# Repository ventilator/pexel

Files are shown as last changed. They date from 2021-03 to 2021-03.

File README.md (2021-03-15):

# pexel
Playing around with penrose tilings, in particular _P2_, which consists of _kites_ and _darts_

3D printed shapes, arranged in the _penrose sun_ pattern, LED back light through laser cut acryl with a Raspberry Pi Pico and MicroPython

20 darts and 25 kites, slowly changing their base color, giving a nice, non distracting back ground mood setting, looked a bit like church window style, in the end 

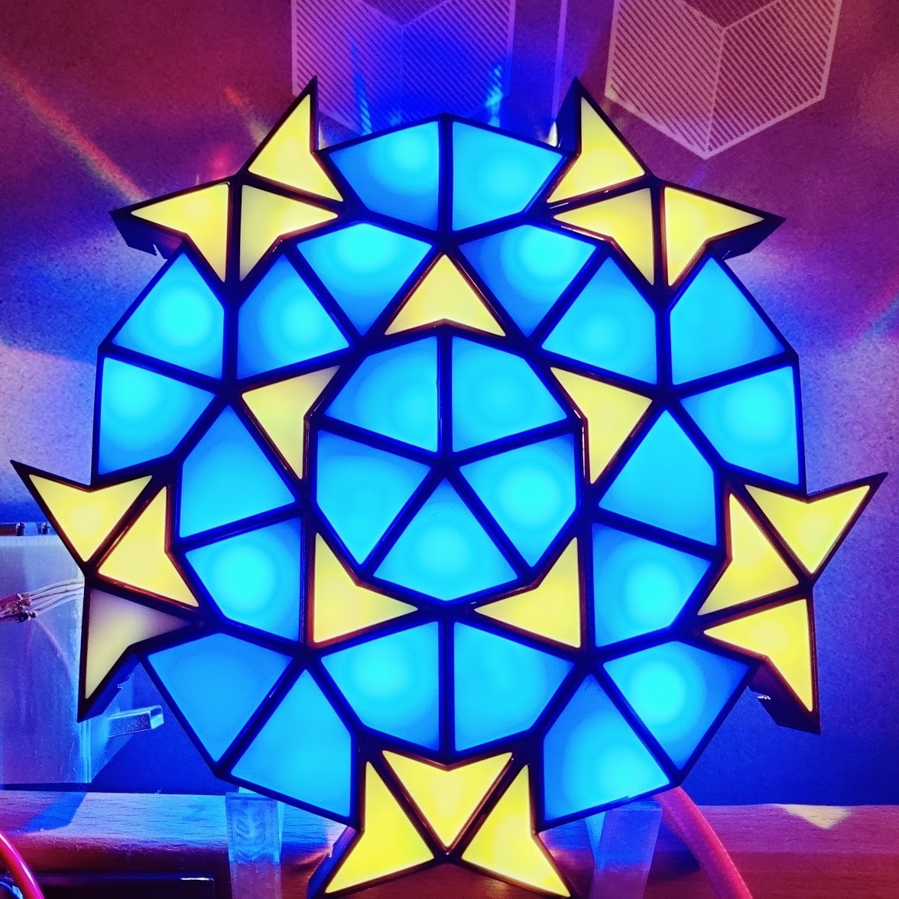
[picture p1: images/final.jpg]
final


cycling through the color wheel every min (or so)

I built it just to explore the _very_ nice Penrose pattern and tinker a bit with 3D-CAD & MicroPython. I learnt a lot in the process

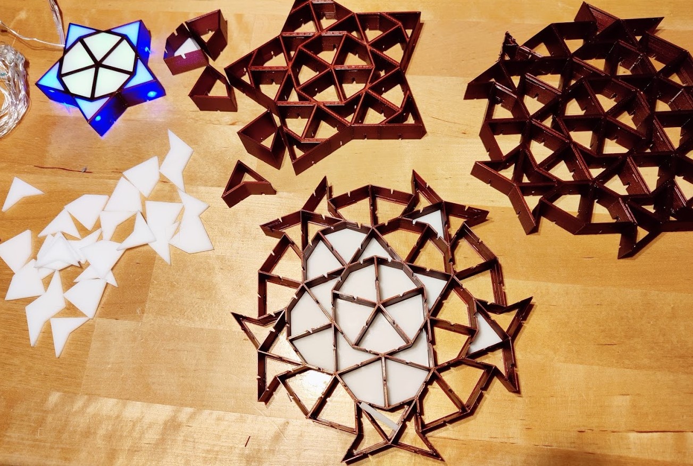
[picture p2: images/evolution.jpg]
evolution


## Material

### scaffolding

Brown-purple filament (Prusament PLA Mystic Brown)
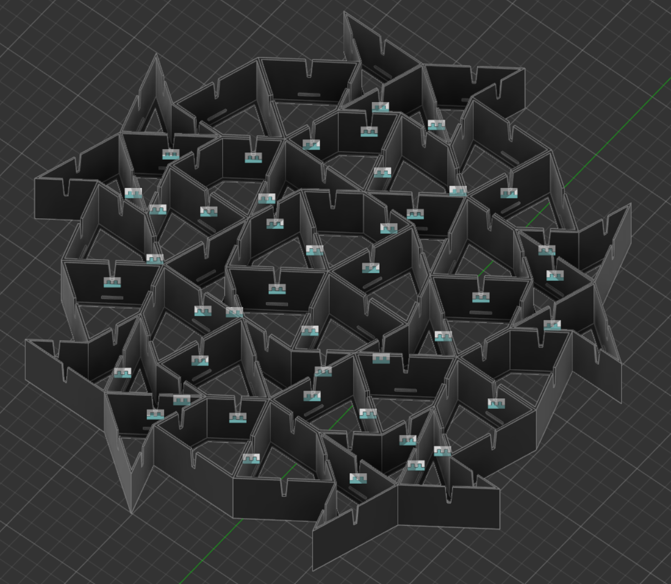
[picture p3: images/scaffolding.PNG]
scaffolding


### backplane

currently open

### LEDs

WS2813 (45 LEDs, single LEDs, kind of cheap even with the traditional stripe, just wires) - they take up very little space in this package variant

### µController

Rasperry Pi Pico RP2040
USB cable

### case RP

housing for the RP: [Thingiverse Model](https://www.thingiverse.com/thing:4750920)

## Assembly

The acrylic pieces should snap in, but on some shaped the retention pins broke of, so I used a bit of hot glue. There are slits for the LED wires from one compartment to the next

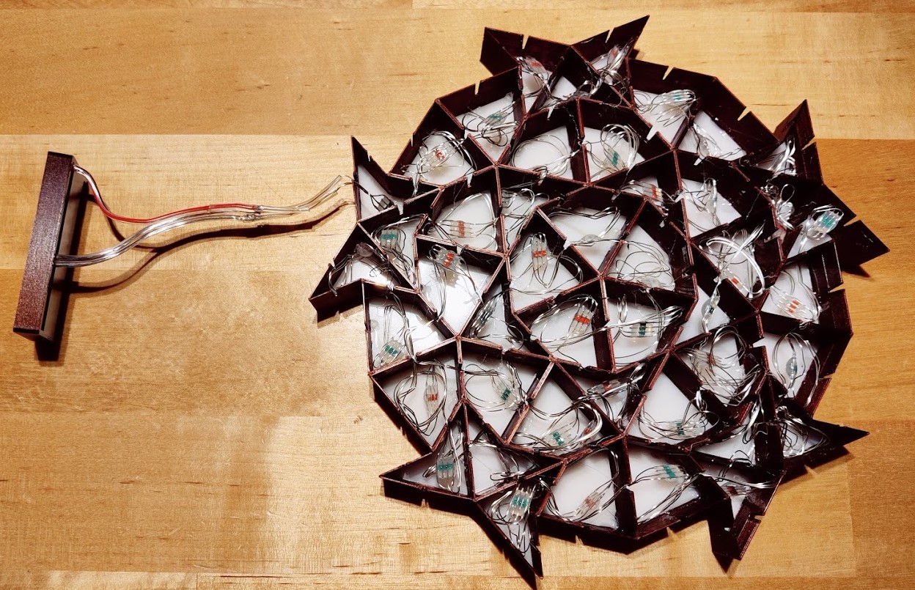
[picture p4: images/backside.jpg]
backside


## Code

RP2040 WS2812 [demonstrator](https://core-electronics.com.au/tutorials/how-to-use-ws2812b-rgb-leds-with-raspberry-pi-pico.html) code, modified to the number of LEDs and the pattern I wanted
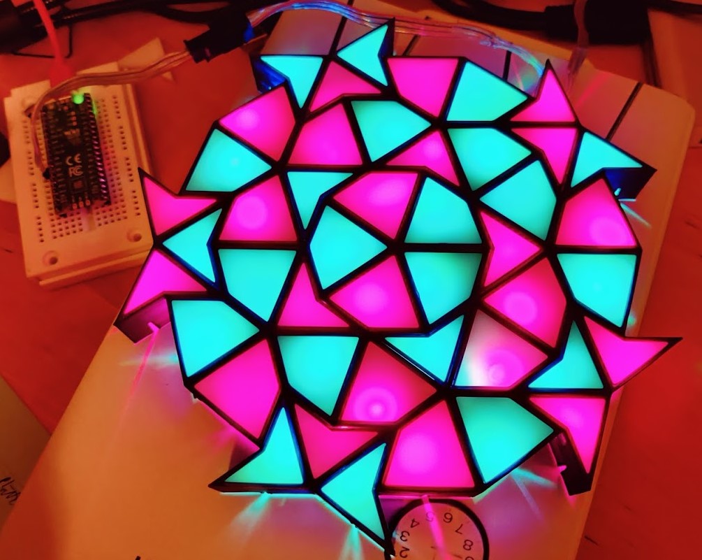
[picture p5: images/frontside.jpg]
frontside


## Kites and Darts

generated with Inkscape to reflect a [Penrose tiling (P2)](https://en.wikipedia.org/wiki/Penrose_tiling#Kite_and_dart_tiling_(P2)) - Its just lines, rotated by 144° or 72° as needed

laser cut white semi transparent acrylic 

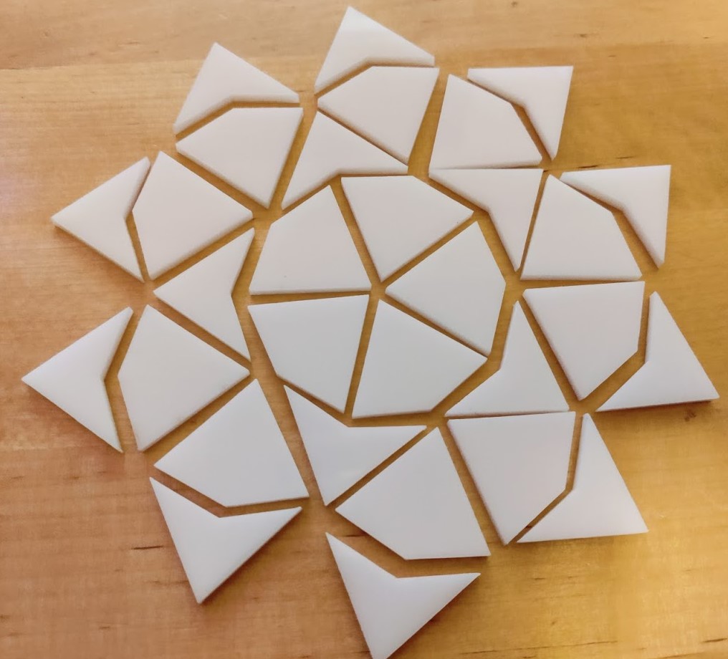
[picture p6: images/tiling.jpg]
tiling


## Scaffolding

generated with Fusion360, design was a bit challenging for me but in general nothing too complex

Interesting part is the 3D Printing part:

* activate thin wall detection in Prusa Slicer
* one can get a nice front side effect by increasing the number of perimeter lines to 4 or 5, so the window bridges are all parallel 

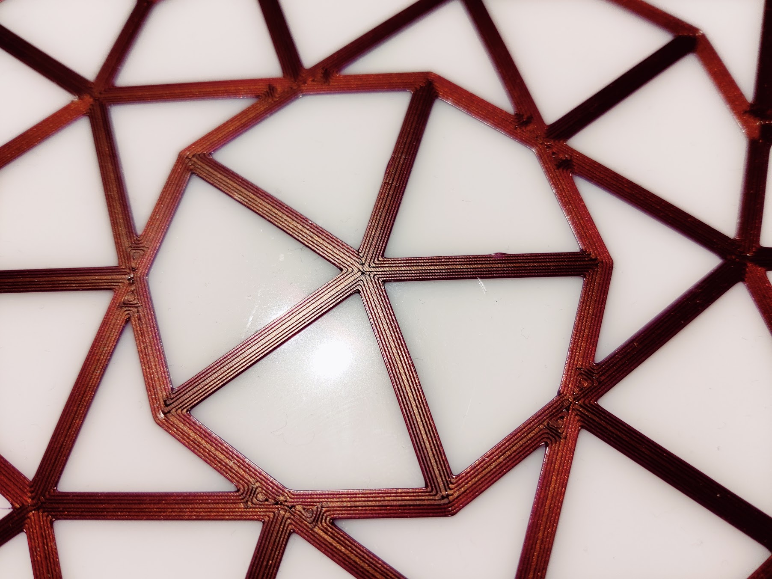
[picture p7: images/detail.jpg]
detail


I printed a lot of discarded versions during the design phase (see evolution image above)

## Assembly

Solder 3 wires to the RPi, pin 22, gnd and 5V

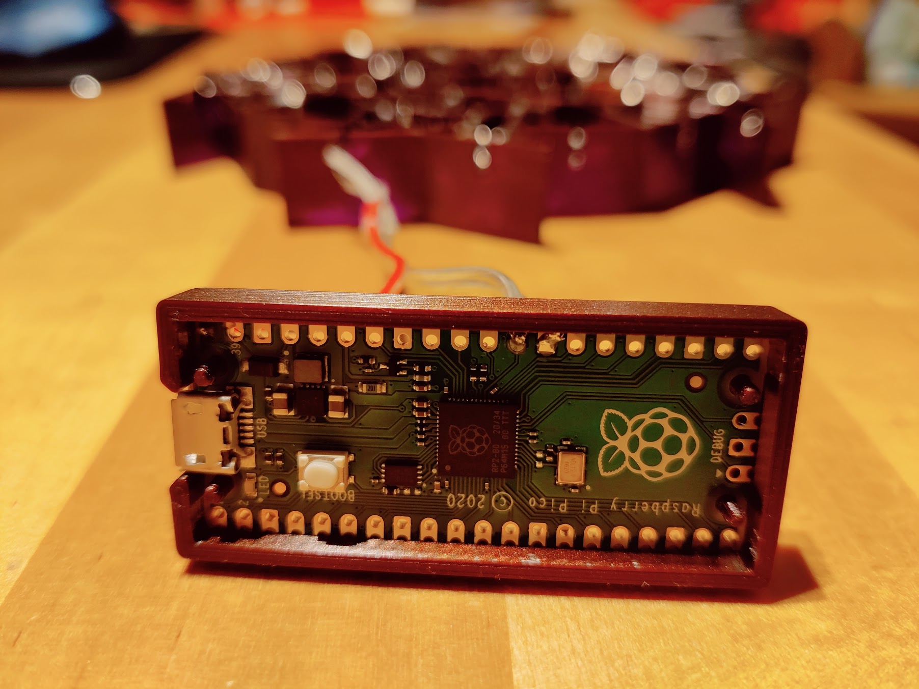
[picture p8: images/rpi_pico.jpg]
rpi_pico


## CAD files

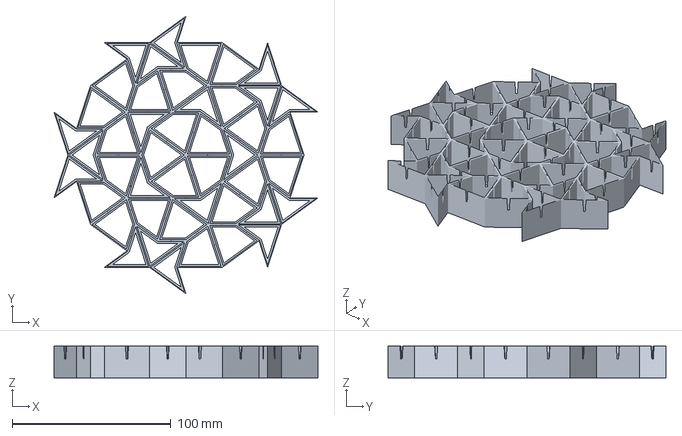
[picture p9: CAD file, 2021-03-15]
scaffolding-3d-printer/penrose-sun v15.3mf
166.5 x 175.1 x 20.0 mm

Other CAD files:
scaffolding-3d-printer/penrose-sun v15.stl

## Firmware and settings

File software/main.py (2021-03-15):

# Example using PIO to drive a set of WS2812 LEDs. Credit https://core-electronics.com.au/tutorials/how-to-use-ws2812b-rgb-leds-with-raspberry-pi-pico.html
# Expansion of demo code by venti

import array, time
from machine import Pin
import rp2

# Configure the number of WS2812 LEDs.
NUM_LEDS = 46
PIN_NUM = 22
brightness = 1
_speed = 1 #delay in seconds for next color

@rp2.asm_pio(sideset_init=rp2.PIO.OUT_LOW, out_shiftdir=rp2.PIO.SHIFT_LEFT, autopull=True, pull_thresh=24)
def ws2812():
    T1 = 2
    T2 = 5
    T3 = 3
    wrap_target()
    label("bitloop")
    out(x, 1)               .side(0)    [T3 - 1]
    jmp(not_x, "do_zero")   .side(1)    [T1 - 1]
    jmp("bitloop")          .side(1)    [T2 - 1]
    label("do_zero")
    nop()                   .side(0)    [T2 - 1]
    wrap()


# Create the StateMachine with the ws2812 program, outputting on pin
sm = rp2.StateMachine(0, ws2812, freq=8_000_000, sideset_base=Pin(PIN_NUM))

# Start the StateMachine, it will wait for data on its FIFO.
sm.active(1)

# Display a pattern on the LEDs via an array of LED RGB values.
ar = array.array("I", [0 for _ in range(NUM_LEDS)])

##########################################################################
def pixels_show():
    dimmer_ar = array.array("I", [0 for _ in range(NUM_LEDS)])
    for i,c in enumerate(ar):
        r = int(((c >> 8) & 0xFF) * brightness)
        g = int(((c >> 16) & 0xFF) * brightness)
        b = int((c & 0xFF) * brightness)
        dimmer_ar[i] = (g<<16) + (r<<8) + b
    sm.put(dimmer_ar, 8)
    time.sleep_ms(10)

def pixels_set(i, color):
    ar[i] = (color[1]<<16) + (color[0]<<8) + color[2]

def pixels_fill(color):
    for i in range(len(ar)):
        pixels_set(i, color)

def colcor_chase(color, wait):
    for i in range(NUM_LEDS):
        pixels_set(i, color)
        time.sleep(wait)
        pixels_show()
    time.sleep(0.2)

def wheel(pos):
    # Input a value 0 to 255 to get a color value.
    # The colours are a transition r - g - b - back to r.
    if pos < 0 or pos > 255:
        return (0, 0, 0)
    if pos < 85:
        return (255 - pos * 3, pos * 3, 0)
    if pos < 170:
        pos -= 85
        return (0, 255 - pos * 3, pos * 3)
    pos -= 170
    return (pos * 3, 0, 255 - pos * 3)


def reainbow_cycle(wait):
    for j in range(255):
        for i in range(NUM_LEDS):
            rc_index = (i * 256 // NUM_LEDS) + j
            pixels_set(i, wheel(rc_index & 255))
        pixels_show()
        time.sleep(wait)

ring0_kite=[41,42,43,44,45]
ring1_dart=[26,29,32,35,40]
ring2_kite=[25,27,28,30,31,33,34,36,37,38,39]
ring2_dart=[4,9,14,19,24]
ring3_kite=[1,2,6,7,11,12,16,17,21,22]
ring3_dart=[0,3,5,8,10,13,15,18,20,23]

def ring(i):
    if i==0:
        return ring0_kite
    if i==1:
        return ring1_dart
    if i==2:
        return ring2_kite
    if i==4:
        return ring2_dart
    if i==3:
        return ring3_kite
    if i==5:
        return ring3_dart
    return []

def kiteanddarts(wait):        
    for j in range(255):
        active_ring = (j//25) % 6       
        color1 = (0 * 256 // NUM_LEDS) + j
        color2 = (NUM_LEDS//2 * 256 // NUM_LEDS) + j
        for i in range(NUM_LEDS):
            rc_index = 0
            if i in ring3_dart or i in ring2_dart or i in ring1_dart:
                rc_index = color1
            if i in ring3_kite or i in ring2_kite or i in ring0_kite:
                rc_index = color2
            if i in ring(active_ring):
                # rc_index = 227 # activate this for a cyclic effect
                pass
            pixels_set(i, wheel(rc_index & 255))
        pixels_show()
        time.sleep(wait)


BLACK = (0, 0, 0)
RED = (255, 0, 0)
YELLOW = (255, 150, 0)
GREEN = (0, 255, 0)
CYAN = (0, 255, 255)
BLUE = (0, 0, 255)
PURPLE = (180, 0, 255)
WHITE = (255, 255, 255)
COLORS = (BLACK, RED, YELLOW, GREEN, CYAN, BLUE, PURPLE, WHITE)

led = Pin(25, Pin.OUT)

while True:
    led.high()
    pixels_fill(RED)
    kiteanddarts(_speed)
    led.low()
